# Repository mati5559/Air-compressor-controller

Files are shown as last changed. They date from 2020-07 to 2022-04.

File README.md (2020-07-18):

# Air-compressor-controller

Controller for my DIY air compressor

# Description

I made air compressor from two washing machine's motors, some tank, air pump and a few other elements. 
Those motors are universal brush motors, so i need some controller to stabilize their speed. 
This controller stabilises motors speed with PID algorithm, turns them on and off at specified pressure and have some other features:
- temperature protection
- oil change interval reminder (It measures working time and turn on LED when oil should be changed) 
- fan control 
- soft start (PID)
- overload protection

In software directory is Eclipse C++ project.
In hardware directory are board and schematic. It should be run with AutoDesk Eagle. 

# WARNING

DIY air compressors are very dangerous. 
There is high voltage in this circuit that can kill you.
High pressure tank also can be dangerous. It can explode.

I did it at my own risk for science and fun. Do not do this by yourself!

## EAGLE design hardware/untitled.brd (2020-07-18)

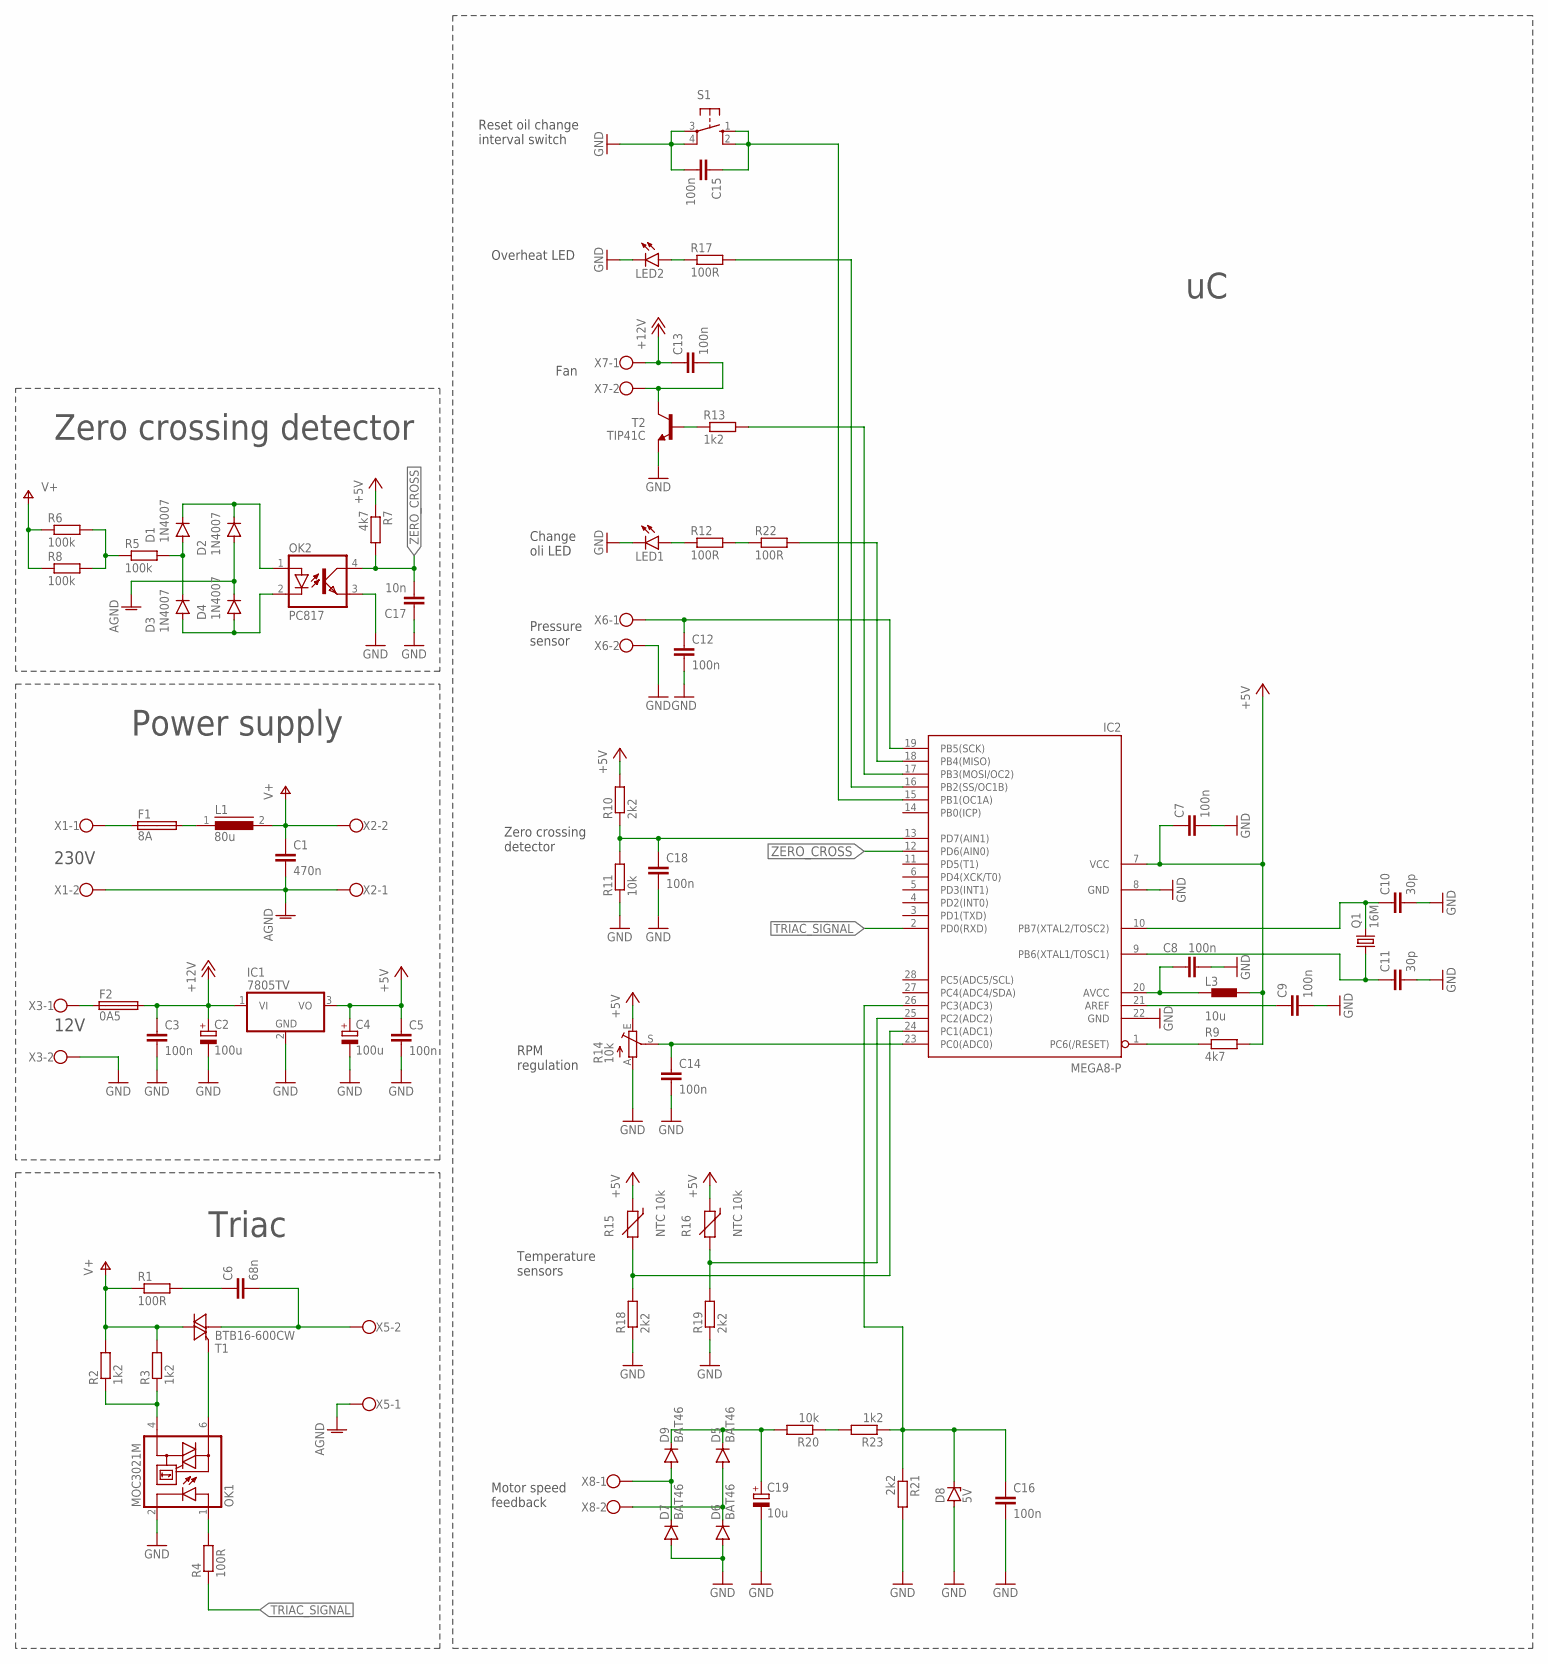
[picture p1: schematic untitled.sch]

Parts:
C1: 470n; C22.5B7
C2, C4: 100u; E3,5-8
C3, C5, C7, C8, C9, C12, C13, C14, C15, C16, C18: 100n; C5B3
C6: 68n; C150-084X183
C10, C11: 30p; C5B3
C17: 10n; C5B3
C19: 10u; E2,5-6
D1, D2, D3, D4: 1N4007; DO41-10
D5, D6, D7, D9: BAT46; DO34-7
D8: 5V; DO34Z7
F1: 8A; SHK20L
F2: 0A5; SHK20L
IC1: 7805TV; TO220V
IC2: MEGA8-P; DIL28-3
L1: 80u; SFT1030
L3: 10u; BL01RN1A
LED1, LED2: LED5MM
OK1: MOC3021M; DIL06
OK2: PC817; DIL04
Q1: 16M; HC49/S
R1, R4, R12, R17, R22: 100R; 0204/7
R2, R3, R13, R23: 1k2; 0204/7
R5, R6, R8: 100k; 0204/7
R7, R9: 4k7; 0204/7
R10, R18, R19, R21: 2k2; 0204/7
R11, R20: 10k; 0204/7
R14: 10k; RJ9W
R15, R16: NTC 10k; R-7,5
S1: 10-XX; B3F-10XX
T1: BTB16-600CW; TO220BV
T2: TIP41C; TO220V
X1, X2, X3, X5, X6, X7, X8: W237-102

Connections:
+5V: C4.+, C5.1, C7.1, IC1.3 (VO), IC2.7 (VCC), L3.2, R7.1, R9.2, R10.2, R14.E, R15.1, R16.1
+12V: C2.+, C3.1, C13.1, F2.2A, IC1.1 (VI), X7.1
AGND: C1.2, D2.A, D4.C, X1.2, X2.1, X5.1
GND: C2.-, C3.2, C4.-, C5.2, C7.2, C8.2, C9.2, C10.2, C11.2, C12.2, C14.2, C15.2, C16.2, C17.1, C18.2, C19.-, D6.A, D7.A, D8.A, IC1.2 (GND), IC2.8 (GND), IC2.22 (GND), LED1.K (C), LED2.K (C), OK1.2 (C), OK2.3 (EMIT), R11.1, R14.A, R18.1, R19.1, R21.2, S1.3, S1.4 (P1), T2.3 (E), X3.2, X6.2
unnamed: F1.1A, X1.1
unnamed: F1.2A, L1.1
unnamed: OK1.6 (A2), T1.G
unnamed: C6.2, T1.T1 (A1), X5.2
unnamed: C6.1, R1.2
unnamed: OK1.4 (A1), R2.1, R3.1
unnamed: F2.1A, X3.1
unnamed: OK1.1 (A), R4.2
unnamed: D1.C, D2.C, OK2.1 (A)
unnamed: D3.A, D4.A, OK2.2 (C)
unnamed: R5.1, R6.2, R8.2
unnamed: D7.C, D9.A, X8.1
unnamed: C18.1, IC2.13 (PD7(AIN1)), R10.1, R11.2
unnamed: C8.1, IC2.20 (AVCC), L3.1
unnamed: C9.1, IC2.21 (AREF)
unnamed: IC2.1 (PC6(/RESET)), R9.1
unnamed: C10.1, IC2.10 (PB7(XTAL2/TOSC2)), Q1.2
unnamed: C11.1, IC2.9 (PB6(XTAL1/TOSC1)), Q1.1
unnamed: C12.1, IC2.19 (PB5(SCK)), X6.1
unnamed: LED1.A, R12.1
unnamed: IC2.18 (PB4(MISO)), R22.2
unnamed: C13.2, T2.2 (C), X7.2
unnamed: R13.1, T2.1 (B)
unnamed: IC2.17 (PB3(MOSI/OC2)), R13.2
unnamed: C14.1, IC2.23 (PC0(ADC0)), R14.S
unnamed: IC2.24 (PC1(ADC1)), R15.2, R18.2
unnamed: IC2.25 (PC2(ADC2)), R16.2, R19.2
unnamed: LED2.A, R17.1
unnamed: IC2.16 (PB2(SS/OC1B)), R17.2
unnamed: C19.+, D5.C, D9.C, R20.2
unnamed: C15.1, IC2.15 (PB1(OC1A)), S1.1 (S), S1.2 (S1)
unnamed: D1.A, D3.C, R5.2
unnamed: D5.A, D6.C, X8.2
unnamed: C16.1, D8.C, IC2.26 (PC3(ADC3)), R21.1, R23.1
unnamed: R12.2, R22.1
unnamed: R20.1, R23.2
TRIAC_SIGNAL: IC2.2 (PD0(RXD)), R4.1
V+: C1.1, L1.2, R1.1, R2.2, R3.2, R6.1, R8.1, T1.T2 (A2), X2.2
ZERO_CROSS: C17.2, IC2.12 (PD6(AIN0)), OK2.4 (COL), R7.2

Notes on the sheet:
230V
12V
Power supply
Triac
Zero crossing detector
Pressure sensor
Change oli LED
Fan
RPM regulation
Temperature sensors
Overheat LED
Reset oil change interval switch
Motor speed feedback
Zero crossing detector

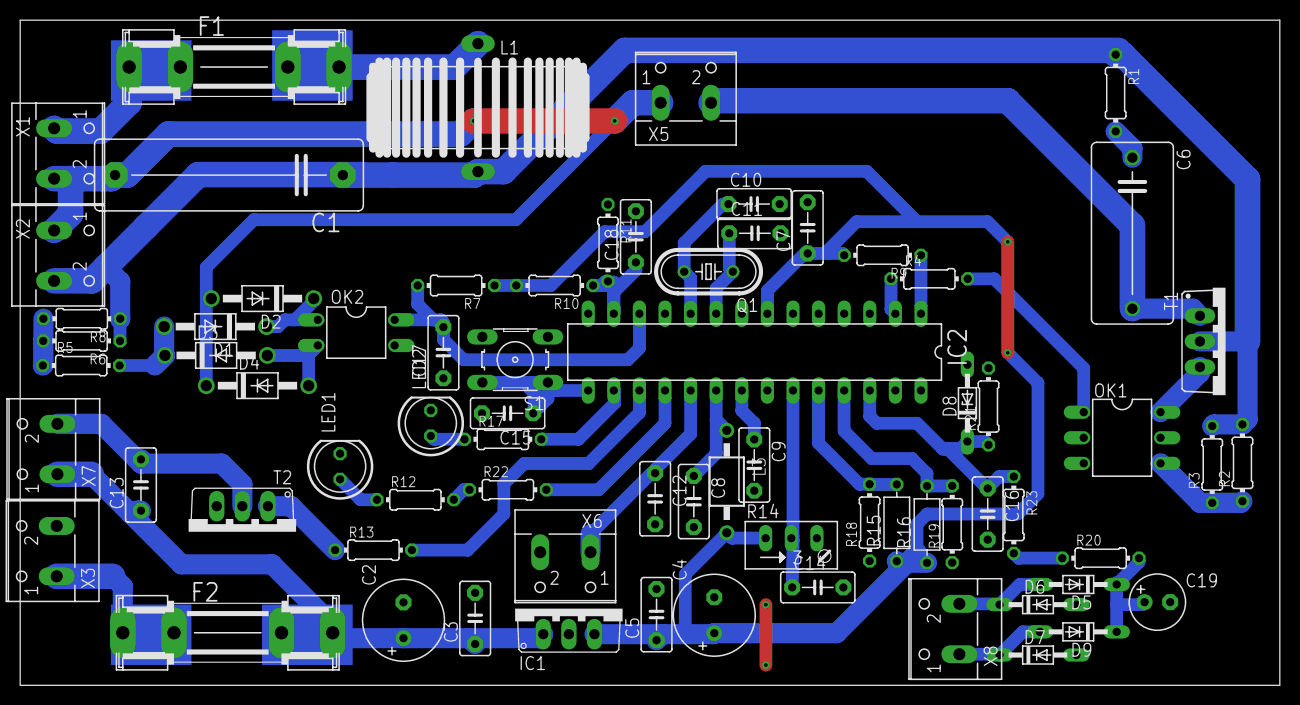
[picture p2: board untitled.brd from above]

Board: 2 copper layers, 125.0 x 66.0 mm, 72 parts (0 on the bottom side), 43 nets.

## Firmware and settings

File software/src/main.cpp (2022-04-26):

/*
 * main.cpp
 *
 * Author: mati5559
 */

#include "main.hpp"


int main()
{
	// Clear watchdog flag
	MCUCSR = 0x00;
	wdt_disable();

	cli();

	// Initialize everything
	_delay_ms(500);
	DDRB 	= 0b00011100; // 0-NC 1-reset oil switch 2-overheat LED 3-fan 4-oil LED 5-pressure sensor
	PORTB 	= 0b00100010; // Pull up oil switch and pressure sensor

	adc::init();
	motor::init();

	sei();

	_delay_ms(500);


	wdt_enable(WDTO_500MS);

	int pressure_sensor_prev_state = 1;
	int thread1 = 0;


	while(1)
	{
		wdt_reset();

		// Make measurements for motor controller
		motor::set_speed_regulator_state(READ_SPEED_REGULATOR);
		motor::set_speed_sensor_state(READ_SPEED);


		// Read pressure sensor and turn on/off motor and fan
		if((PRESSURE_SENSOR_STATE == 1) && (pressure_sensor_prev_state == 0))
		{
			pressure_sensor_prev_state = 1;
			motor::stop();

			_delay_ms(200);
			wdt_reset();

			// Add current working time to EEPROM
			if(motor::working_time > 0)
			{
				eeprom::add_time(motor::working_time/100);
				motor::working_time = 0;
			}

			// Fan will work for some time after motor stop
			for(int a = 0; a < (FAN_OFF_DELAY/100); a++)
			{
				wdt_reset();
				_delay_ms(100);
			}
			FAN_OFF;
		}
		if((PRESSURE_SENSOR_STATE == 0) && (pressure_sensor_prev_state == 1))
		{
			pressure_sensor_prev_state = 0;
			FAN_ON;
			motor::start();

			wdt_reset();
			_delay_ms(100);
			wdt_reset();
		}

		// "Pseudo-multithreading"
		if(thread1>20)
		{
			thread1 = 0;

			// Temperature protection
			if(READ_TMP_1 > MAX_TMP_1)
			{
				motor::stop();
				OVERHEAT_LED_ON;
				FAN_ON;

				while((MAX_TMP_1 - READ_TMP_1) < TMP_HYSTERESIS_1)
				{
					wdt_reset();
					_delay_ms(150);
				}

				pressure_sensor_prev_state = 1;
				FAN_OFF;
				OVERHEAT_LED_OFF;
			}
			if(READ_TMP_2 > MAX_TMP_2)
			{
				motor::stop();
				OVERHEAT_LED_ON;
				FAN_ON;

				while((MAX_TMP_2 - READ_TMP_2) < TMP_HYSTERESIS_2)
				{
					wdt_reset();
					_delay_ms(150);
				}

				pressure_sensor_prev_state = 1;
				FAN_OFF;
				OVERHEAT_LED_OFF;
			}




			// Read working time from EEPROM and check if it is greater than time between oil changes
			if(eeprom::get_time() > OIL_INTERVAL)
			{
				OIL_LED_ON;
			}

			wdt_reset();

			// Reset working time if button is pressed
			if(OIL_SWITCH_STATE == 0)
			{
				_delay_us(100);
				eeprom::reset_time();
				OIL_LED_OFF;

				while(OIL_SWITCH_STATE == 0)
				{
					wdt_reset();
				}
			}
		}

		thread1++;
	}

	return 0;
}

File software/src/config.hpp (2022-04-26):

/*
 * config.hpp
 *
 * Author: mati5559
 */

#ifndef CONFIG_HPP_
#define CONFIG_HPP_



// Delay between motor off and fan off [ms]
#define FAN_OFF_DELAY 5000



// Time of triac gate pulse [us]
#define PULSE_TIME 500



// Max time between zero cross detection and turn on triac [us]
// It should be lower than 10000 (for 50Hz) because of zero crossing detector imperfection
#define MAX_TRIAC_DELAY 9000




// Target voltage on speed sensor
//
// TARGED_SPEED = (int) 33,6 * U
// U - speed sensor voltage for target RPM
#define TARGET_SPEED 650



// Gain of PID regulator
#define MOTOR_GAIN_P 0.4
#define MOTOR_GAIN_I 0.002
#define MOTOR_GAIN_D 11.0



// Range of speed regulation potentiometer
// Lower number = wider regulation range
// It must be integer greater than 0
// In my case 5 seems regulation range about 1000 RPM
#define SPEED_REGULATION_RANGE 5



// Circuit has two temperature sensors
// Motor stop if MAX_TMP_x exceed values below
// Motor automatically starts if temperature falls below MAX_TMP_x - TMP_HYSERERSIS_x
//
// MAX_TMP_x = 2250600 / (Rt + 2200)
// TMP_HYSTERESIS_x = (2250600 / (Rt + 2200)) - (2250600 / (Rm + 2200))
// Rt - resistance of sensor in max temperature [ohm]
// Rm - resistance of sensor in temperature, that motor should turn on
#define MAX_TMP_1 600
#define TMP_HYSTERESIS_1 150

#define MAX_TMP_2 600
#define TMP_HYSTERESIS_2 150



// Lifetime of air pump oil [s]
// After this time oil change led will turn on
// 180000 is about 50 hours
#define OIL_INTERVAL 180000

#endif /* CONFIG_HPP_ */

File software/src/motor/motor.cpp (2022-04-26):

#include "motor.hpp"


namespace motor
{
	unsigned long int working_time = 0;

	int on_time = 0; // Time in us * 2

	int timer2_counter = 0;

	int speed_regulator_state = 0;

	int speed_sensor_state = 0;

	int state = MOTOR_STATE_OFF;

	void init()
	{
		// PD0 as output
		DDRD |= 0b00000001;

		// Analog comparator (zero crossing detection)
		SFIOR &= 0b11110111;
		ACSR = 0b00001010;


		// Timer 1
		TCCR1A = 0b00000000;
		TCCR1B = 0b00001000;

		// Timer 2
		TCCR2 = 0b00001111; // prescaler 1024
		OCR2 = 156; // about 20 ms

		// Turn on interrupts from timers
		TIMSK = 0b10010000;
	}

	void start()
	{
		state = MOTOR_STATE_ON;
	}

	void stop()
	{
		state = MOTOR_STATE_ON;
	}

	void set_speed_regulator_state(int state)
	{
		speed_regulator_state = state;
	}

	void set_speed_sensor_state(int state)
	{
		speed_sensor_state = state;
	}
}


// Executed when zero cross detected
ISR(ANA_COMP_vect)
{
	if(motor::on_time > (MAX_TRIAC_DELAY *2)) motor::on_time = MAX_TRIAC_DELAY * 2;
	if(motor::on_time <= 1) return;


	OCR1A = ((MAX_TRIAC_DELAY * 2) - (motor::on_time))+1; // Time in us * 2
	TCCR1B |= 0b00000010; // Start timer
}



// Executed some time after zero cross
ISR(TIMER1_COMPA_vect)
{
	TCCR1B &= 0b11111000; // Stop timer
	TCNT1 = 0x0000; // Reset timer

	PORTD |= 0b00000001;

	_delay_us(PULSE_TIME);

	PORTD &= 0b11111110;

	if(motor::state == MOTOR_STATE_ON)
	{
		motor::working_time++;
	}
}



// Executed every 20ms
ISR(TIMER2_COMP_vect)
{
	// Timer 2 is 8-bit timer so additional variable is needed to execute instructions every 100ms
	motor::timer2_counter++;

	// Executed every 100ms
	if(motor::timer2_counter>=5)
	{
		motor::timer2_counter = 0;


		// PID algorithm
		static int prev_error = 0;
		static int integral = 0;

		int error = ((TARGET_SPEED + (motor::speed_regulator_state / SPEED_REGULATION_RANGE)) - motor::speed_sensor_state);

		integral += error;

		if(motor::state == MOTOR_STATE_ON)
		{
			motor::on_time += (int) ((double) MOTOR_GAIN_P * error) + ((double) MOTOR_GAIN_I * integral) + ((double) MOTOR_GAIN_D * (error-prev_error));
		}
		else if(motor::state == MOTOR_STATE_OFF)
		{
			integral = 0;
			prev_error = 0;
			error = 0;
			motor::on_time = 0;
		}


		// Turn off and blink overheat LED if motor is stuck or if speed sensor is broken
		if(motor::on_time>9000 && error > 350 && motor::working_time > 400)
		{
			motor::on_time = 0;
			cli();
			wdt_reset();

			while(1)
			{
				for(int i = 0; i < 10; i++)
				{
					_delay_ms(100);
					wdt_reset();
				}

				OVERHEAT_LED_ON;

				for(int i = 0; i < 10; i++)
				{
					_delay_ms(100);
					wdt_reset();
				}

				OVERHEAT_LED_OFF;
			}
		}

		prev_error = error;

	}
}

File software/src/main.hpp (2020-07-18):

#ifndef MAIN_HPP_
#define MAIN_HPP_

#include <avr/io.h>
#include <avr/wdt.h>
#include <util/delay.h>

#include "adc/adc.hpp"
#include "motor/motor.hpp"
#include "eeprom/eeprom.hpp"

// Some definitions
#define OIL_SWITCH_STATE ((PINB & 0b00000010)>>1)
#define PRESSURE_SENSOR_STATE ((PINB & 0b00100000)>>5)

#define OVERHEAT_LED_ON PORTB |= 0b00000100
#define OVERHEAT_LED_OFF PORTB &= 0b11111011

#define FAN_ON PORTB |= 0b00001000
#define FAN_OFF PORTB &= 0b11110111

#define OIL_LED_ON PORTB |= 0b00010000
#define OIL_LED_OFF PORTB &= 0b11101111


#endif /* MAIN_HPP_ */
